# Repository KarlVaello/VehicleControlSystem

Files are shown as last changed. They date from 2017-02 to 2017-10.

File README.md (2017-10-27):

# Vehicle Control System

### What is VCS?
In modern vehicles almost 80% of the vehicle is controlled electronically. That's just VCS, a control system. Focused on electric vehicles but can be easily modified for other types.
VCS consists of several units and modules, all connected by an area network bus, based on rs-485 and my own [data protocol](https://github.com/KarlVaello/VCS/wiki/Unit-Communication-protocol), allowing modularization.
In this project you will find both the hardware and the software of each unit or module.

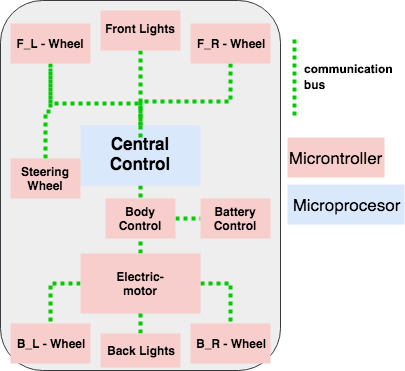
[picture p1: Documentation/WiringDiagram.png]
Wiring Diagram

 Electronic control units / modules
 
UNITS:
- CCU Central Control Unit
	- CCU Cluster Control Unit
	- CCU Central Control Unit
- EmCU Electric-motor Control Unit
- BCU Battery Control Unit

MODULES:
- CcCM Central-console Control Module
- SteeringWheel Control Module
- BCM Body Control Module
- BlCM Back-lights Control Module
- FlCM Front-lights Control Module

### SCREENSHOTS

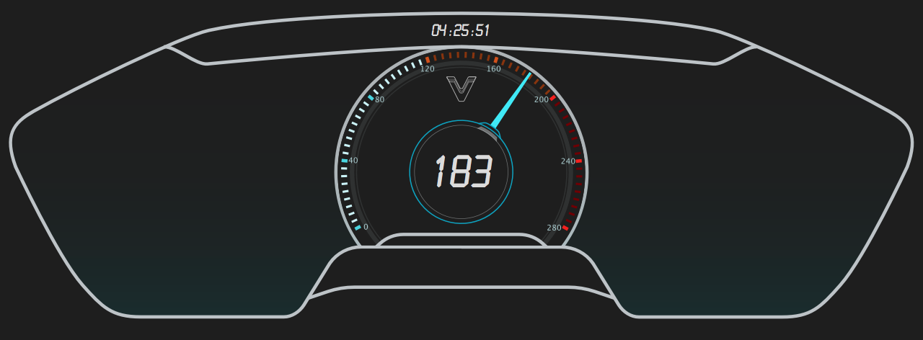
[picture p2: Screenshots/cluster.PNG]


BASE MODULE

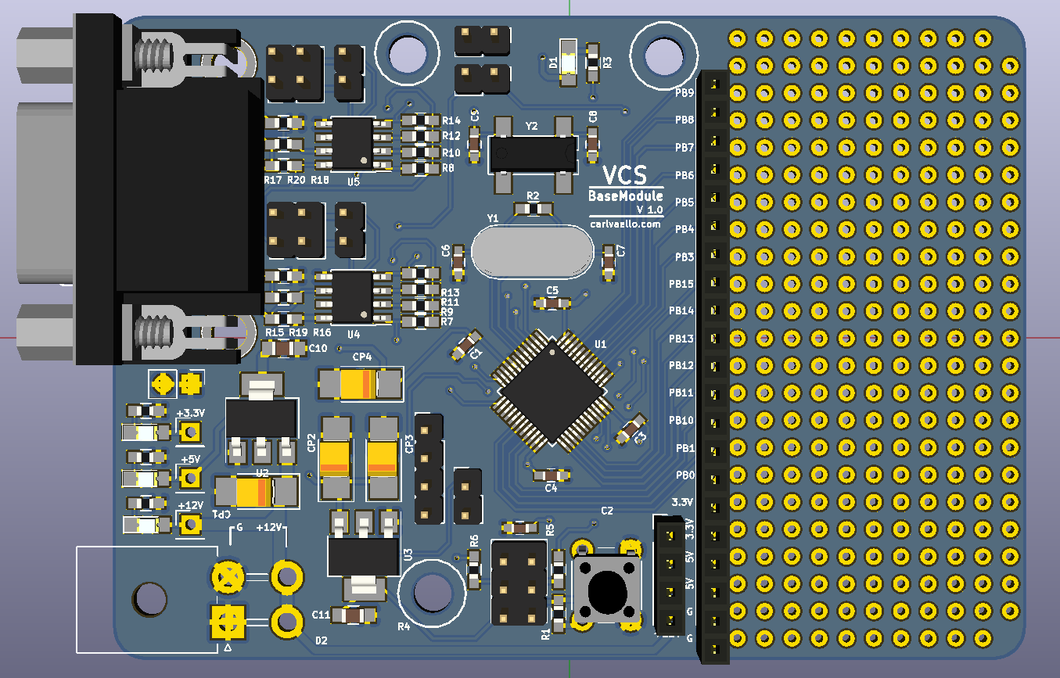
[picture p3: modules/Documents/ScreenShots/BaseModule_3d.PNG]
Base Module 3d

 
# Full Documentation

See the [WIKI](https://github.com/KarlVaello/VCS/wiki) for full documentation, examples, operational details and other information.

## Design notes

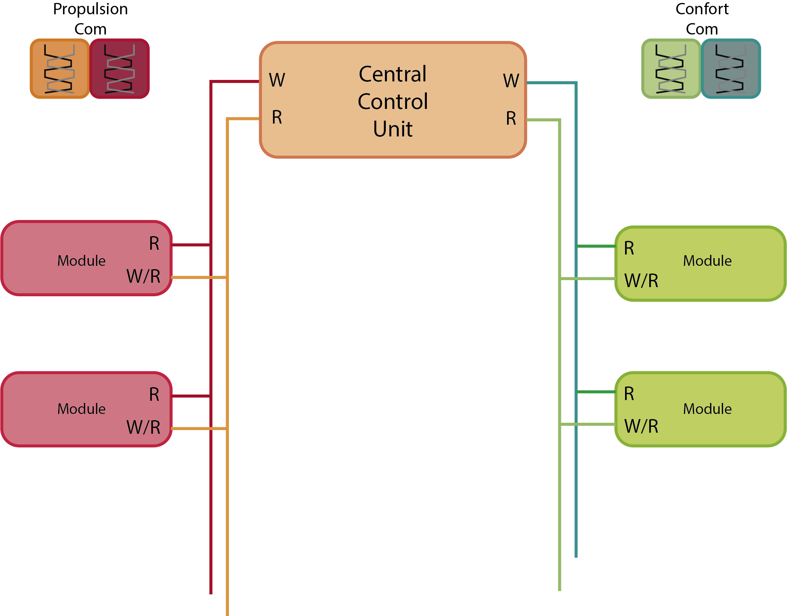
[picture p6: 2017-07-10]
Documentation/UnitCommunication_diagram.png

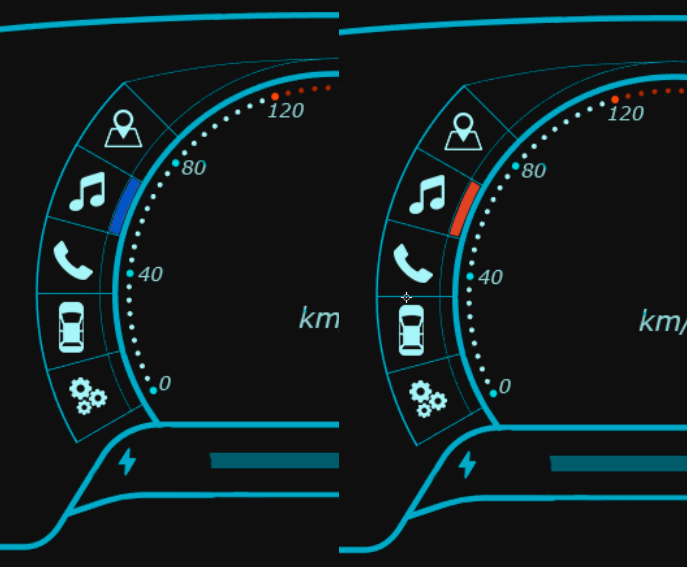
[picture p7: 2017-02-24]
Screenshots/UISketching.png

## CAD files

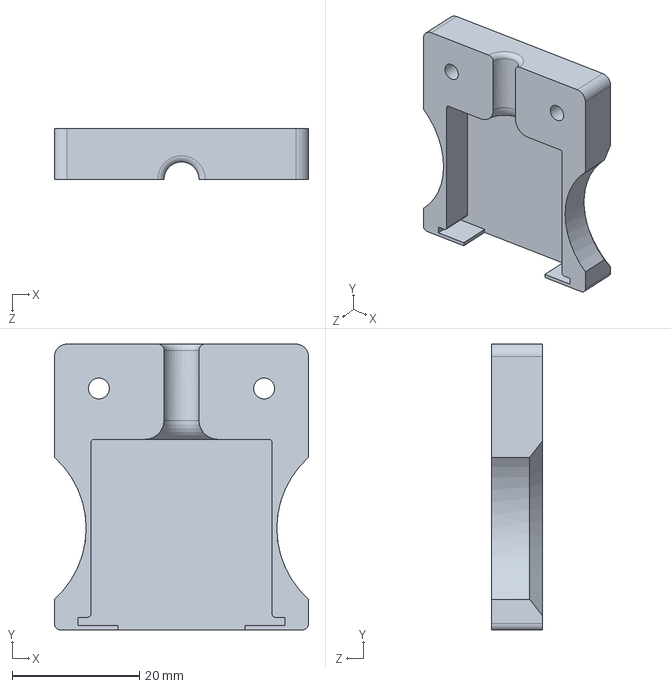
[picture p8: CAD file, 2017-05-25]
Other/DB9_SINGLE.SLDPRT
40.0 x 45.0 x 8.00 mm

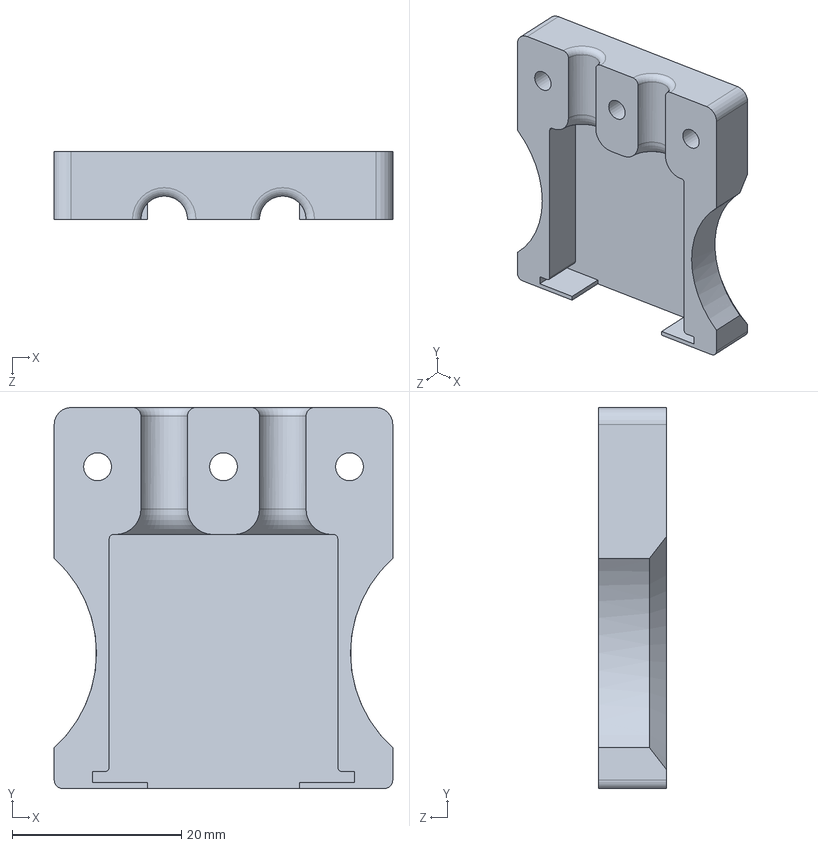
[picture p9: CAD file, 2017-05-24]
Other/DB9_DUAL.SLDPRT
40.0 x 45.0 x 8.00 mm

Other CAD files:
Other/DB9_DUAL.STL
Other/DB9_SINGLE.STL

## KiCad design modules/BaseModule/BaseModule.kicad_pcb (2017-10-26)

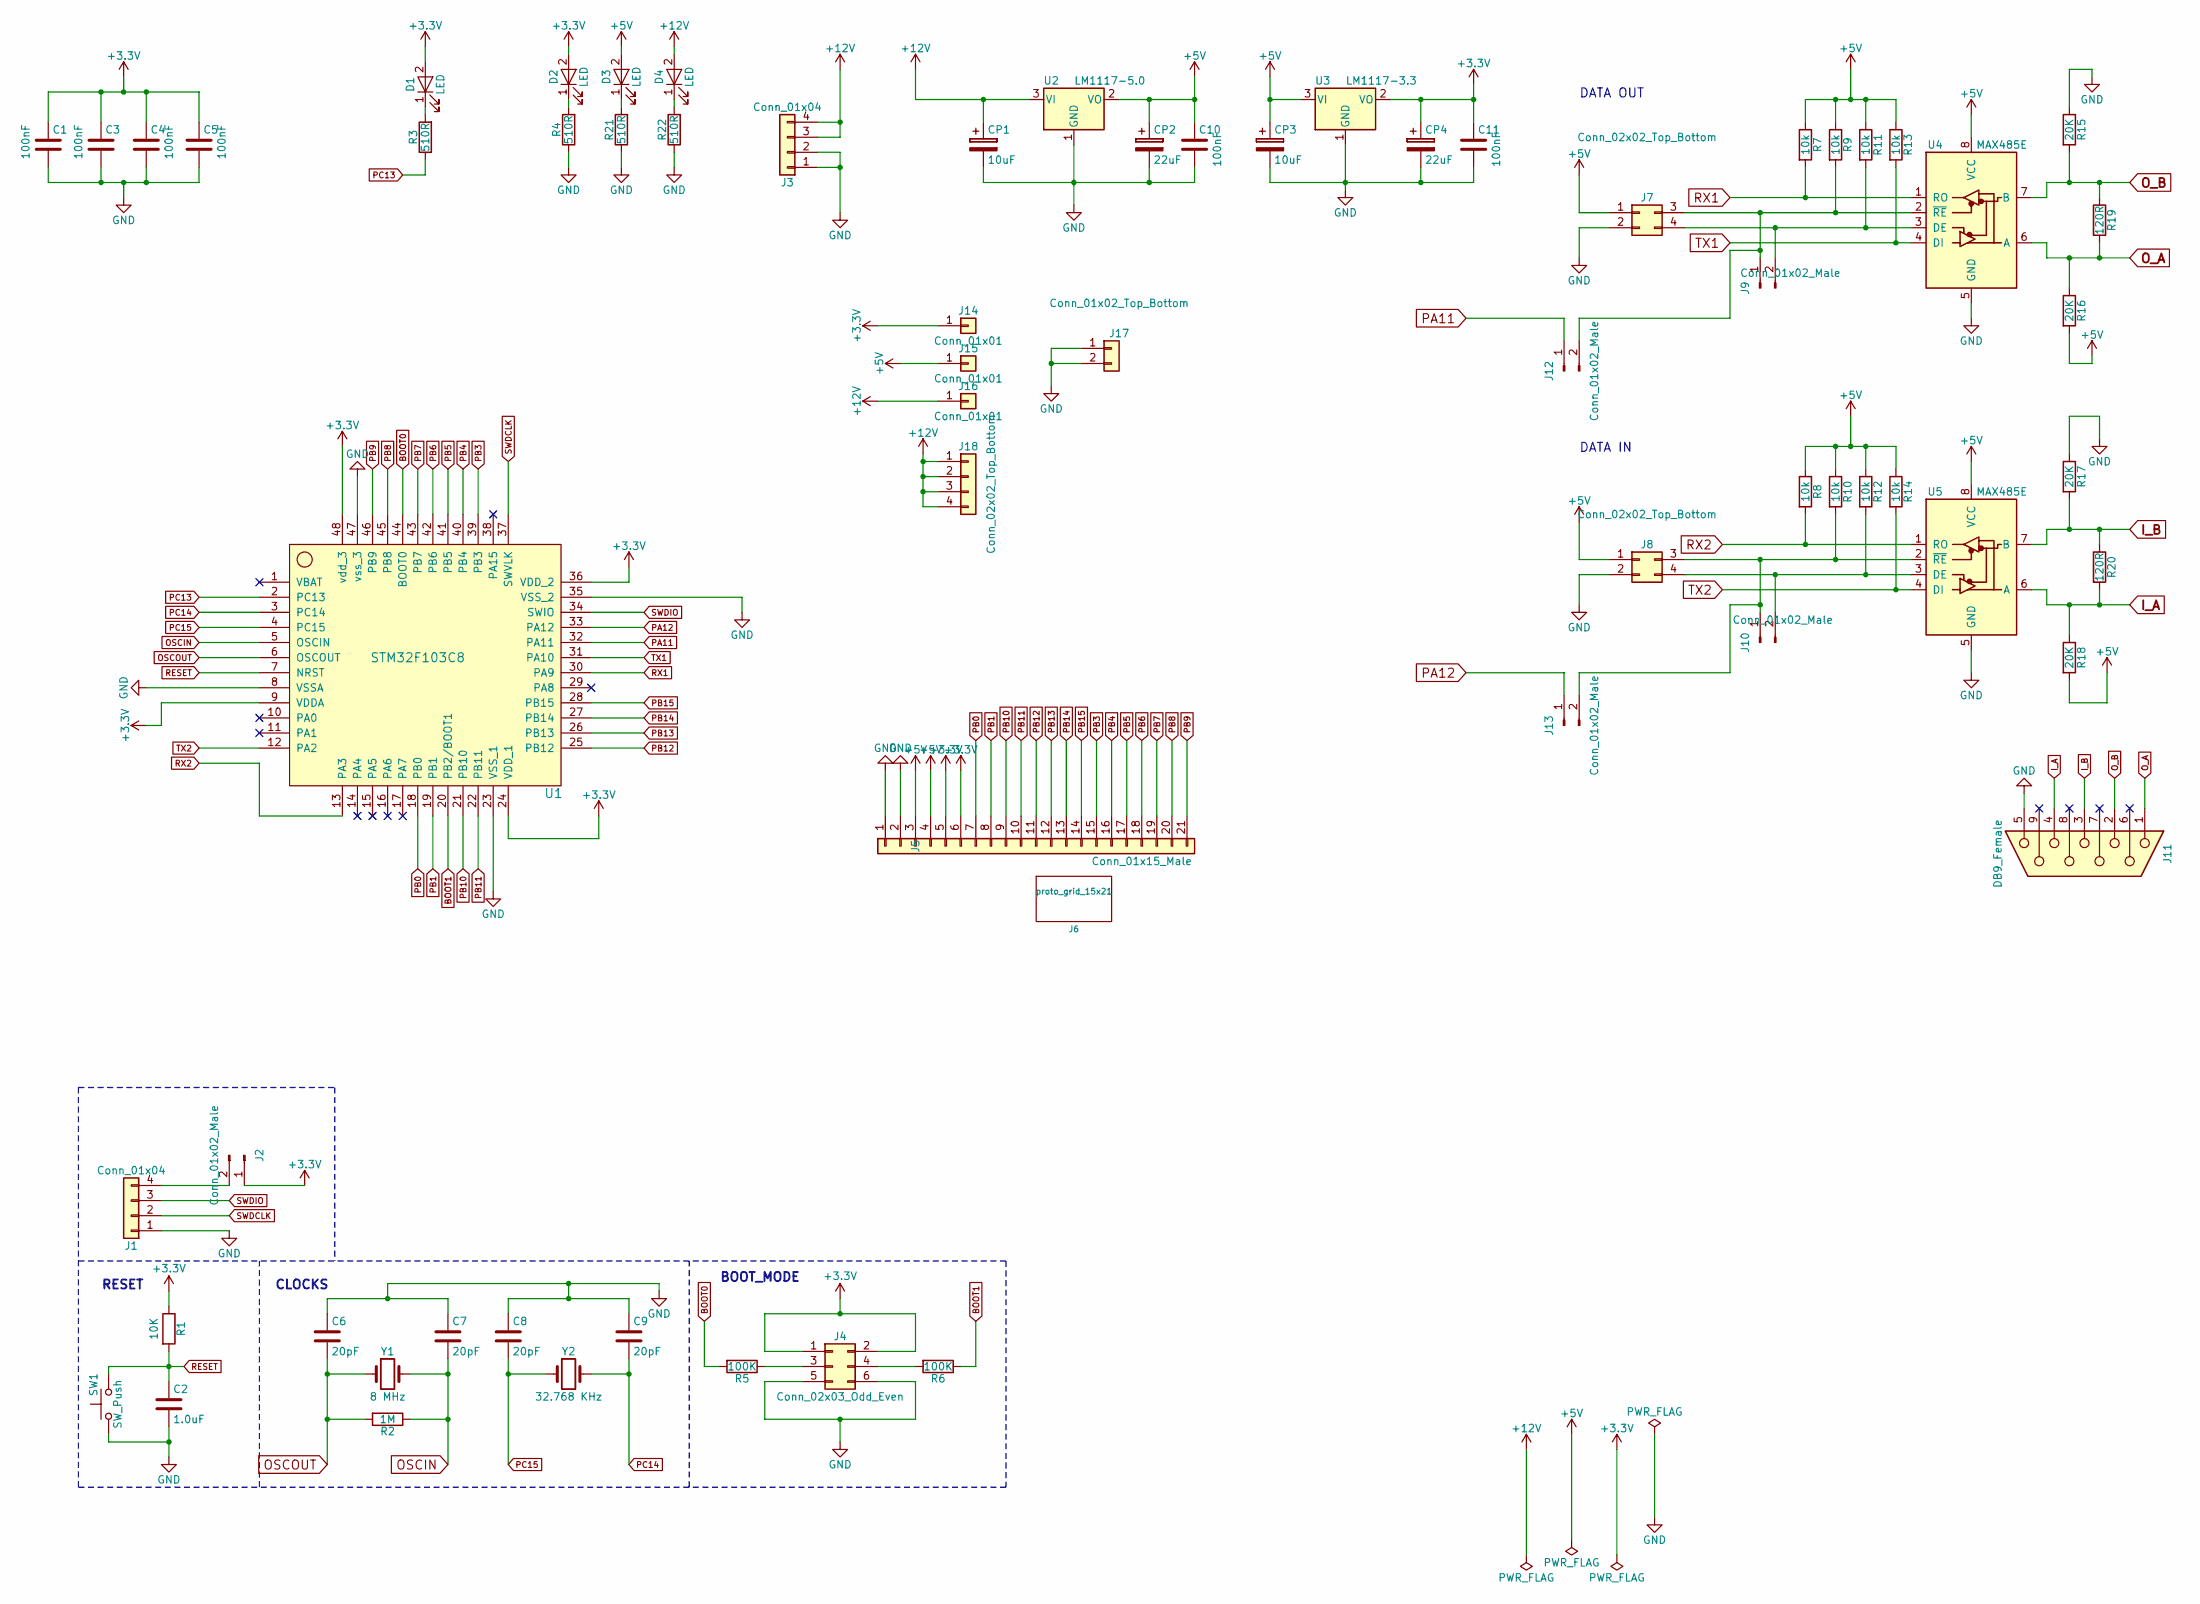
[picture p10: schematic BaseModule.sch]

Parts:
C1, C3, C4, C5: 100nF; C_0603_HandSoldering
C2: 1.0uF; C_0603_HandSoldering
C6, C7, C8, C9: 20pF; C_0603_HandSoldering
C10, C11: 100nF; C_0805_HandSoldering
CP1, CP3: 10uF; CP_Tantalum_Case-B_EIA-3528-21_Hand
CP2, CP4: 22uF; CP_Tantalum_Case-B_EIA-3528-21_Hand
D1, D2, D3, D4: LED; LED_0805_HandSoldering
J1: Conn_01x04; Pin_Header_Straight_1x04_Pitch2.54mm
J2, J9, J10, J12, J13: Conn_01x02_Male; Pin_Header_Straight_1x02_Pitch2.54mm
J3: Conn_01x04; Molex_MiniFit-JR-5569-04A2_2x02x4.20mm_Angled
J4: Conn_02x03_Odd_Even; Pin_Header_Straight_2x03_Pitch2.54mm
J5: Conn_01x15_Male; Socket_Strip_Straight_1x21_Pitch2.54mm
J6: proto_grid_15x21; grid
J7, J8: Conn_02x02_Top_Bottom; Pin_Header_Straight_2x02_Pitch2.54mm
J11: DB9_Female
J14, J15, J16: Conn_01x01; Pin_Header_Straight_1x01_Pitch2.54mm
J17: Conn_01x02_Top_Bottom; Pin_Header_Straight_1x02_Pitch2.54mm
J18: Conn_02x02_Top_Bottom; Socket_Strip_Straight_1x04_Pitch2.54mm
R1: 10K; R_0603_HandSoldering
R2: 1M; R_0603_HandSoldering
R3, R4, R21, R22: 510R; R_0603_HandSoldering
R5, R6: 100K; R_0603_HandSoldering
R7, R8, R9, R10, R11, R12, R13, R14: 10k; R_0603_HandSoldering
R15, R16, R17, R18: 20K; R_0603_HandSoldering
R19, R20: 120R; R_0603_HandSoldering
SW1: SW_Push; SW_PUSH_6mm_h8.5mm
U1: STM32F103C8; LQFP-48_7x7mm_Pitch0.5mm
U2: LM1117-5.0; SOT-223
U3: LM1117-3.3; SOT-223
U4, U5: MAX485E; SOIC-8_3.9x4.9mm_Pitch1.27mm
Y1: 8 MHz; Crystal_HC49-4H_Vertical
Y2: 32.768 KHz; Crystal_SMD_SeikoEpson_MC306-4pin_8.0x3.2mm_HandSoldering

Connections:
+3V3: C1.1, C3.1, C4.1, C5.1, C11.1, CP4.1, D1.2 (A), D2.2 (A), J2.1, J4.1, J4.2, J5.5, J5.6, J14.1, R1.1, U1.9 (VDDA), U1.24 (VDD_1), U1.36 (VDD_2), U1.48 (vdd_3), U3.2 (VO)
+5V: C10.1, CP2.1, CP3.1, D3.2 (A), J5.3, J5.4, J7.1, J8.1, J15.1, R7.1, R8.1, R9.1, R10.1, R11.1, R12.1, R13.1, R14.1, R16.2, R18.2, U2.2 (VO), U3.3 (VI), U4.8 (VCC), U5.8 (VCC)
+12V: CP1.1, D4.2 (A), J3.3, J3.4, J16.1, J18.1, J18.2, J18.3, J18.4, U2.3 (VI)
BOOT0: R5.2, U1.44 (BOOT0)
BOOT1: R6.1, U1.20 (PB2/BOOT1)
GND: C1.2, C2.2, C3.2, C4.2, C5.2, C6.1, C7.1, C8.1, C9.1, C10.2, C11.2, CP1.2, CP2.2, CP3.2, CP4.2, J1.1, J3.1, J3.2, J4.5, J4.6, J5.1, J5.2, J7.2, J8.2, J11.5, J17.1, J17.2, R4.1, R15.1, R17.1, R21.1, R22.1, SW1.1, U1.8 (VSSA), U1.23 (VSS_1), U1.35 (VSS_2), U1.47 (vss_3), U2.1 (GND), U3.1 (GND), U4.5 (GND), U5.5 (GND)
I_A: J11.4, R18.1, R20.2, U5.6 (A)
I_B: J11.3, R17.2, R20.1, U5.7 (B)
unnamed: D1.1 (K), R3.2
unnamed: D2.1 (K), R4.2
unnamed: D3.1 (K), R21.2
unnamed: D4.1 (K), R22.2
unnamed: J1.4, J2.2
unnamed: J4.3, R5.1
unnamed: J4.4, R6.2
unnamed: J7.4, J9.2, R11.2, U4.3 (DE)
unnamed: J8.3, J10.1, J13.2, R10.2, U5.2 (~RE)
unnamed: J8.4, J10.2, R12.2, U5.3 (DE)
unnamed: J7.3, J9.1, J12.2, R9.2, U4.2 (~RE)
OSCIN: C7.2, R2.1, U1.5 (OSCIN), Y1.2
OSCOUT: C6.2, R2.2, U1.6 (OSCOUT), Y1.1
O_A: J11.1, R16.1, R19.2, U4.6 (A)
O_B: J11.2, R15.2, R19.1, U4.7 (B)
PA11: J12.1, U1.32 (PA11)
PA12: J13.1, U1.33 (PA12)
PB0: J5.7, U1.18 (PB0)
PB1: J5.8, U1.19 (PB1)
PB3: J5.15, U1.39 (PB3)
PB4: J5.16, U1.40 (PB4)
PB5: J5.17, U1.41 (PB5)
PB6: J5.18, U1.42 (PB6)
PB7: J5.19, U1.43 (PB7)
PB8: J5.20, U1.45 (PB8~)
PB9: J5.21, U1.46 (PB9)
PB10: J5.9, U1.21 (PB10)
PB11: J5.10, U1.22 (PB11)
PB12: J5.11, U1.25 (PB12)
PB13: J5.12, U1.26 (PB13)
PB14: J5.13, U1.27 (PB14)
PB15: J5.14, U1.28 (PB15)
PC13: R3.1, U1.2 (PC13)
PC14: C9.2, U1.3 (PC14), Y2.2
PC15: C8.2, U1.4 (PC15), Y2.1
RESET: C2.1, R1.2, SW1.2, U1.7 (NRST)
RX1: R7.2, U1.30 (PA9), U4.1 (RO)
RX2: R8.2, U1.13 (PA3), U5.1 (RO)
SWDCLK: J1.2, U1.37 (SWVLK)
SWDIO: J1.3, U1.34 (SWIO)
TX1: R13.2, U1.31 (PA10), U4.4 (DI)
TX2: R14.2, U1.12 (PA2), U5.4 (DI)

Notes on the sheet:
DATA OUT
DATA IN
RESET
CLOCKS
BOOT_MODE

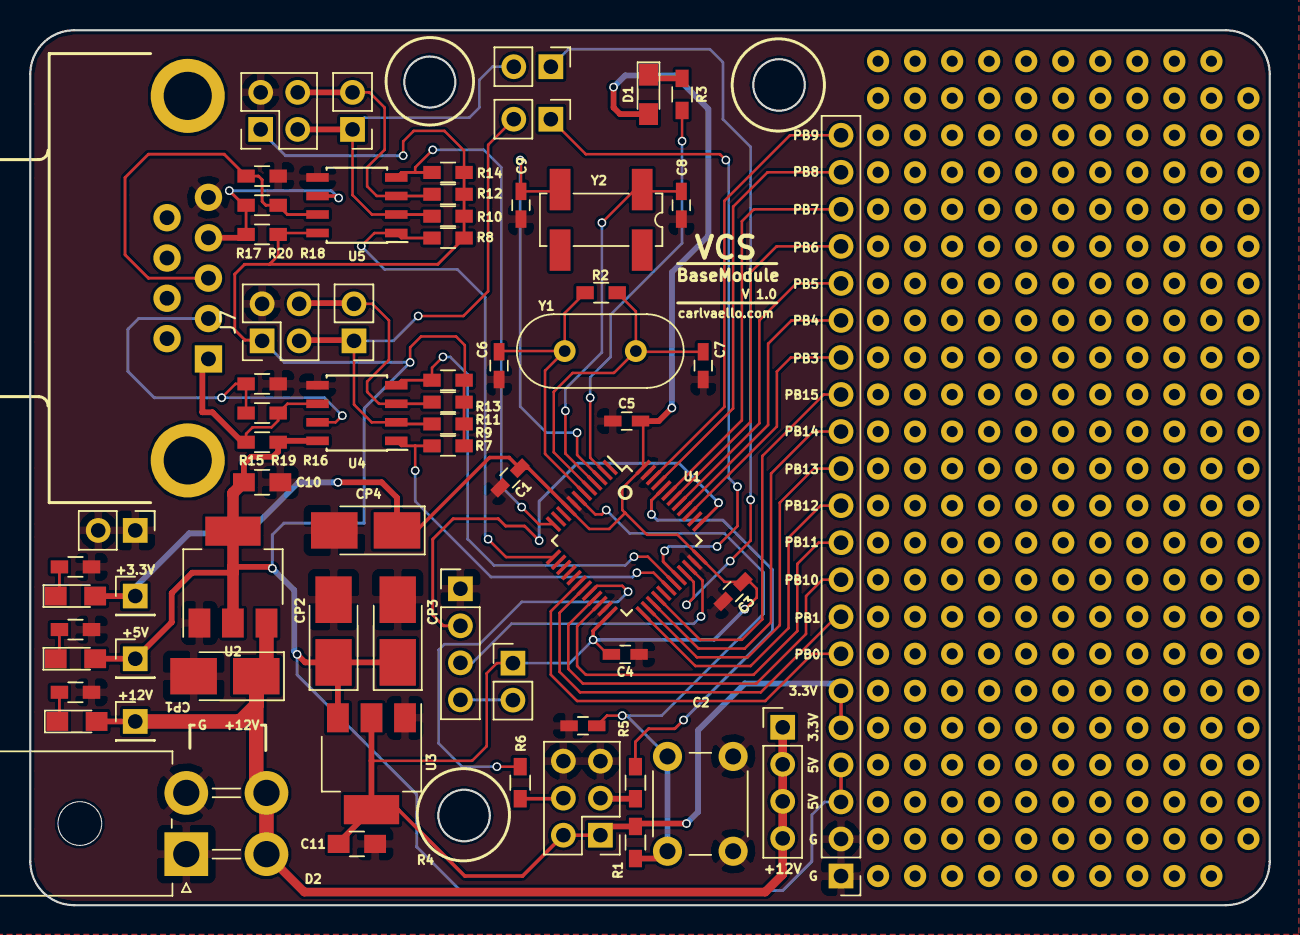
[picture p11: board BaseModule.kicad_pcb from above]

Board: 2 copper layers, 85.0 x 60.0 mm, 67 parts (0 on the bottom side), 50 nets.

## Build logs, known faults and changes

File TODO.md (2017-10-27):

## CCU - Central Control Unit

 ### TO DO (Software):
 Graphics
 - [ ] Complete UI graphics implementation
 - [x] speedPointer graphics implementation
 - [x] outline graphics implementation
 
 Communication
 - [ ] COMUNICATION between CCU and units. communicatión planning (physical laye rs-485)
 - [x] Bad data recived detection
 - [x] Propulsion Communication planning
 - [ ] Propulsion Communication wiki
 - [x] Propulsion Communication base code (that allow test)
 - [x] Propulsion Communication chek units
 - [x] FULL Propulsion Communication
 - [ ] Comfort Communication planning
 - [ ] Comfort Communication wiki
 - [ ] Comfort Communication base code (that allow test)
 - [ ] FULL communication working
 
 - [ ] FULL documentation and wiki about communication between units
 
 Warning / Errors
 - [ ] Warning and errors (UI whill show an icon when something fails and a message that explain de fail)

 	Warning and error are separated classes, every new error or warning is a new object. They will be store and we will be able to access to warnings and errors independtly.
 - [ ] Errors and Warling list and wiki 

 	Errors: 
 	- [ ] Communication error, some devicer not respond or is missing, depends of the missing devices it will show error or warning icon.

 	- [ ] P-Brake  error
 	- [ ] Spoiler error
	- [ ] Spoiler error
	- [ ] ...

 	Warnings:

 	- [ ] Battery warning

	more...

## CCU - Modules

 ### TO DO (SoftWare):
  - [x] Emiter base code
  - [X] Receiver base code
  - [X] Dual R/W base code
  - [ ] Data collion detecion

 ### TO DO (Hardware):

 - [X] BaseBoard planning (v1.0)
 - [X] BaseBoard Schematic(v1.0)
 - [X] BaseBoard Board(v1.0)
 - [X] FULL BaseBoard design(v1.0)
 - [ ] BaseBoard test PCB (asssembled and tested)(v1.0)
 - [ ] BaseBoard FINAL PCB (asssembled and tested)(v1.0)

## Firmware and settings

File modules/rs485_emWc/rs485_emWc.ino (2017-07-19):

/*
  Code that allow you to test dual rs-458, one to read incoming data and one to write data

*/
int incomingByte = 0;

int wSpeed = 0;
int a = true;

void setup() {
  Serial1.begin(115200);
  Serial2.begin(115200);
  pinMode(PC13, OUTPUT);
  pinMode(PB7, OUTPUT);

  digitalWrite(PC13, LOW);   // turn the LED on (HIGH is the voltage level)
  delay(100);              // wait for a second
  digitalWrite(PC13, HIGH);    // turn the LED off by making the voltage LOW
  delay(100);
  digitalWrite(PC13, LOW);   // turn the LED on (HIGH is the voltage level)
  delay(100);              // wait for a second
  digitalWrite(PC13, HIGH);    // turn the LED off by making the voltage LOW
  delay(100);
  digitalWrite(PC13, LOW);   // turn the LED on (HIGH is the voltage level)
  delay(100);              // wait for a second
  digitalWrite(PC13, HIGH);    // turn the LED off by making the voltage LOW
  delay(500);

  digitalWrite(PB7, HIGH);    //mx485 write mode
}


void loop() {

  if (a) {
    wSpeed = wSpeed + 130; 
    if (wSpeed >= 28000) { //280.00
      a = false;
    }
  } else {
    wSpeed = wSpeed - 130;
    if (wSpeed <= 0) {
      a = true;
    }
  }

  sendDataMessage(0, 1, 0, 0, 0, 0, 0, 0, 0, 0, 0);
  delay(40);

}

void sendDataMessage(int b0, int b1, int b2, int b3, int b4, int b5, int b6,
                     int b7, int b8, int b9, int b10) {

  Serial1.write(b0); //B0// reciverID (to who is send)
  Serial1.write(b1); //B1// senderID (who sends the message)
  Serial1.write(b2); //B2// dataID [(0x00)

  String fSpeed = convertIntTo16bitHex(wSpeed);
 
  Serial1.write(convertStringHexTo8bInt(fSpeed.substring(4, 8))); //B4// d1
  Serial1.write(convertStringHexTo8bInt(fSpeed.substring(0, 4))); //B3// d0

  Serial1.write(b5); //B5// d2
  Serial1.write(b6); //B6// d3
  Serial1.write(b7); //B7// d4
  Serial1.write(b8); //B8// d5
  Serial1.write(b9); //B9// d6
  Serial1.write(b10); //B10// d7

  float ercSum = b0 + b1 + b2 + convertStringHexTo8bInt(fSpeed.substring(4, 8)) + convertStringHexTo8bInt(fSpeed.substring(0, 4)) + b5 + b6 + b7 + b8 + b9 + b10;

  String ercSum_P1 = convertIntTo16bitHex (ercSum);
  int ercSum_P2 = convertStringHexTo8bInt(ercSum_P1.substring(0, 4));
  int ercSum_P3 = convertStringHexTo8bInt(ercSum_P1.substring(4, 8));
  Serial1.write(ercSum_P2); //B11// erc0
  Serial1.write(ercSum_P3); //B12// erc1
}


String convertIntTo16bitHex (int n) {
  float n0 = (float) n / 16.0f;
  float n1 = (float) n0 / 16.0f;
  float n2 = (float) n1 / 16.0f;
  float n3 = (float) n2 / 16.0f;

  int h0 = round(n) % 16;
  int h1 = int(n0) % 16;
  int h2 = int(n1) % 16;
  int h3 = int(n2) % 16;

  return "0x" + String(hexFormating(h3)) + String(hexFormating(h2)) + "0x" + String(hexFormating(h1)) + String(hexFormating(h0)) ;
  //0x320x10
}

char hexFormating(int eToHex) {
  char a = ' ';
  switch (eToHex) {
    case 0:
      a = '0';
      break;
    case 1:
      a = '1';
      break;
    case 2:
      a = '2';
      break;
    case 3:
      a = '3';
      break;
    case 4:
      a = '4';
      break;
    case 5:
      a = '5';
      break;
    case 6:
      a = '6';
      break;
    case 7:
      a = '7';
      break;
    case 8:
      a = '8';
      break;
    case 9:
      a = '9';
      break;
    case 10:
      a = 'A';
      break;
    case 11:
      a = 'B';
      break;
    case 12:
      a = 'C';
      break;
    case 13:
      a = 'D';
      break;
    case 14:
      a = 'E';
      break;
    case 15:
      a = 'F';
      break;
    default:
      break;
  }
  return a;
}

int convertStringHexTo8bInt(String stringHex) {

  int value = 0;

  String stringHexTrimg0 = stringHex.substring(3, 4);
  String stringHexTrimg1 = stringHex.substring(2, 3);

  if (stringHexTrimg0.equals("A")) {
    value = value + 10;
  } else if (stringHexTrimg0.equals("B")) {
    value = value + 11;
  } else if (stringHexTrimg0.equals("C")) {
    value = value + 12;
  } else if (stringHexTrimg0.equals("D")) {
    value = value + 13;
  } else if (stringHexTrimg0.equals("E")) {
    value = value + 14;
  } else if (stringHexTrimg0.equals("F")) {
    value = value + 15;
  } else {
    value = value + stringHexTrimg0.toInt();
  }

  if (stringHexTrimg1.equals("A")) {
    value = value + (10 * 16);
  } else if (stringHexTrimg1.equals("B")) {
    value = value + (11 * 16);
  } else if (stringHexTrimg1.equals("C")) {
    value = value + (12 * 16);
  } else if (stringHexTrimg1.equals("D")) {
    value = value + (13 * 16);
  } else if (stringHexTrimg1.equals("E")) {
    value = value + (14 * 16);
  } else if (stringHexTrimg1.equals("F")) {
    value = value + (15 * 16);
  } else {
    value = value + (stringHexTrimg1.toInt() * 16);
  }

  return value;
}

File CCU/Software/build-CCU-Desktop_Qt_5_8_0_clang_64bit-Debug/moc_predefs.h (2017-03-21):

#define OBJC_NEW_PROPERTIES 1
#define _LP64 1
#define __APPLE_CC__ 6000
#define __APPLE__ 1
#define __ATOMIC_ACQUIRE 2
#define __ATOMIC_ACQ_REL 4
#define __ATOMIC_CONSUME 1
#define __ATOMIC_RELAXED 0
#define __ATOMIC_RELEASE 3
#define __ATOMIC_SEQ_CST 5
#define __BIGGEST_ALIGNMENT__ 16
#define __BLOCKS__ 1
#define __BYTE_ORDER__ __ORDER_LITTLE_ENDIAN__
#define __CHAR16_TYPE__ unsigned short
#define __CHAR32_TYPE__ unsigned int
#define __CHAR_BIT__ 8
#define __CONSTANT_CFSTRINGS__ 1
#define __DBL_DECIMAL_DIG__ 17
#define __DBL_DENORM_MIN__ 4.9406564584124654e-324
#define __DBL_DIG__ 15
#define __DBL_EPSILON__ 2.2204460492503131e-16
#define __DBL_HAS_DENORM__ 1
#define __DBL_HAS_INFINITY__ 1
#define __DBL_HAS_QUIET_NAN__ 1
#define __DBL_MANT_DIG__ 53
#define __DBL_MAX_10_EXP__ 308
#define __DBL_MAX_EXP__ 1024
#define __DBL_MAX__ 1.7976931348623157e+308
#define __DBL_MIN_10_EXP__ (-307)
#define __DBL_MIN_EXP__ (-1021)
#define __DBL_MIN__ 2.2250738585072014e-308
#define __DECIMAL_DIG__ __LDBL_DECIMAL_DIG__
#define __DEPRECATED 1
#define __DYNAMIC__ 1
#define __ENVIRONMENT_MAC_OS_X_VERSION_MIN_REQUIRED__ 1090
#define __EXCEPTIONS 1
#define __FINITE_MATH_ONLY__ 0
#define __FLT_DECIMAL_DIG__ 9
#define __FLT_DENORM_MIN__ 1.40129846e-45F
#define __FLT_DIG__ 6
#define __FLT_EPSILON__ 1.19209290e-7F
#define __FLT_EVAL_METHOD__ 0
#define __FLT_HAS_DENORM__ 1
#define __FLT_HAS_INFINITY__ 1
#define __FLT_HAS_QUIET_NAN__ 1
#define __FLT_MANT_DIG__ 24
#define __FLT_MAX_10_EXP__ 38
#define __FLT_MAX_EXP__ 128
#define __FLT_MAX__ 3.40282347e+38F
#define __FLT_MIN_10_EXP__ (-37)
#define __FLT_MIN_EXP__ (-125)
#define __FLT_MIN__ 1.17549435e-38F
#define __FLT_RADIX__ 2
#define __FXSR__ 1
#define __GCC_ATOMIC_BOOL_LOCK_FREE 2
#define __GCC_ATOMIC_CHAR16_T_LOCK_FREE 2
#define __GCC_ATOMIC_CHAR32_T_LOCK_FREE 2
#define __GCC_ATOMIC_CHAR_LOCK_FREE 2
#define __GCC_ATOMIC_INT_LOCK_FREE 2
#define __GCC_ATOMIC_LLONG_LOCK_FREE 2
#define __GCC_ATOMIC_LONG_LOCK_FREE 2
#define __GCC_ATOMIC_POINTER_LOCK_FREE 2
#define __GCC_ATOMIC_SHORT_LOCK_FREE 2
#define __GCC_ATOMIC_TEST_AND_SET_TRUEVAL 1
#define __GCC_ATOMIC_WCHAR_T_LOCK_FREE 2
#define __GCC_HAVE_SYNC_COMPARE_AND_SWAP_1 1
#define __GCC_HAVE_SYNC_COMPARE_AND_SWAP_16 1
#define __GCC_HAVE_SYNC_COMPARE_AND_SWAP_2 1
#define __GCC_HAVE_SYNC_COMPARE_AND_SWAP_4 1
#define __GCC_HAVE_SYNC_COMPARE_AND_SWAP_8 1
#define __GNUC_GNU_INLINE__ 1
#define __GNUC_MINOR__ 2
#define __GNUC_PATCHLEVEL__ 1
#define __GNUC__ 4
#define __GNUG__ 4
#define __GXX_ABI_VERSION 1002
#define __GXX_EXPERIMENTAL_CXX0X__ 1
#define __GXX_RTTI 1
#define __GXX_WEAK__ 1
#define __INT16_C_SUFFIX__ 
#define __INT16_FMTd__ "hd"
#define __INT16_FMTi__ "hi"
#define __INT16_MAX__ 32767
#define __INT16_TYPE__ short
#define __INT32_C_SUFFIX__ 
#define __INT32_FMTd__ "d"
#define __INT32_FMTi__ "i"
#define __INT32_MAX__ 2147483647
#define __INT32_TYPE__ int
#define __INT64_C_SUFFIX__ LL
#define __INT64_FMTd__ "lld"
#define __INT64_FMTi__ "lli"
#define __INT64_MAX__ 9223372036854775807LL
#define __INT64_TYPE__ long long int
#define __INT8_C_SUFFIX__ 
#define __INT8_FMTd__ "hhd"
#define __INT8_FMTi__ "hhi"
#define __INT8_MAX__ 127
#define __INT8_TYPE__ signed char
#define __INTMAX_C_SUFFIX__ L
#define __INTMAX_FMTd__ "ld"
#define __INTMAX_FMTi__ "li"
#define __INTMAX_MAX__ 9223372036854775807L
#define __INTMAX_TYPE__ long int
#define __INTMAX_WIDTH__ 64
#define __INTPTR_FMTd__ "ld"
#define __INTPTR_FMTi__ "li"
#define __INTPTR_MAX__ 9223372036854775807L
#define __INTPTR_TYPE__ long int
#define __INTPTR_WIDTH__ 64
#define __INT_FAST16_FMTd__ "hd"
#define __INT_FAST16_FMTi__ "hi"
#define __INT_FAST16_MAX__ 32767
#define __INT_FAST16_TYPE__ short
#define __INT_FAST32_FMTd__ "d"
#define __INT_FAST32_FMTi__ "i"
#define __INT_FAST32_MAX__ 2147483647
#define __INT_FAST32_TYPE__ int
#define __INT_FAST64_FMTd__ "ld"
#define __INT_FAST64_FMTi__ "li"
#define __INT_FAST64_MAX__ 9223372036854775807L
#define __INT_FAST64_TYPE__ long int
#define __INT_FAST8_FMTd__ "hhd"
#define __INT_FAST8_FMTi__ "hhi"
#define __INT_FAST8_MAX__ 127
#define __INT_FAST8_TYPE__ signed char
#define __INT_LEAST16_FMTd__ "hd"
#define __INT_LEAST16_FMTi__ "hi"
#define __INT_LEAST16_MAX__ 32767
#define __INT_LEAST16_TYPE__ short
#define __INT_LEAST32_FMTd__ "d"
#define __INT_LEAST32_FMTi__ "i"
#define __INT_LEAST32_MAX__ 2147483647
#define __INT_LEAST32_TYPE__ int
#define __INT_LEAST64_FMTd__ "ld"
#define __INT_LEAST64_FMTi__ "li"
#define __INT_LEAST64_MAX__ 9223372036854775807L
#define __INT_LEAST64_TYPE__ long int
#define __INT_LEAST8_FMTd__ "hhd"
#define __INT_LEAST8_FMTi__ "hhi"
#define __INT_LEAST8_MAX__ 127
#define __INT_LEAST8_TYPE__ signed char
#define __INT_MAX__ 2147483647
#define __LDBL_DECIMAL_DIG__ 21
#define __LDBL_DENORM_MIN__ 3.64519953188247460253e-4951L
#define __LDBL_DIG__ 18
#define __LDBL_EPSILON__ 1.08420217248550443401e-19L
#define __LDBL_HAS_DENORM__ 1
#define __LDBL_HAS_INFINITY__ 1
#define __LDBL_HAS_QUIET_NAN__ 1
#define __LDBL_MANT_DIG__ 64
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

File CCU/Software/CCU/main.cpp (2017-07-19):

#include <QApplication>

#include "cluster.h"
#include <QtSvg/QtSvg>
#include <QtSvg/QSvgRenderer>
#include <cameraStream.h>
#include <unitCommunication.h>
#include <infotainment.h>

int main(int argc, char *argv[])
{
    QApplication app(argc, argv);
    Infotainment *infotainment = new Infotainment();

    UnitCommunication *centralControlUnit_COM = new UnitCommunication(infotainment);
    centralControlUnit_COM->startCom(infotainment);

    Cluster *cluster = new Cluster(0,centralControlUnit_COM,infotainment);

    //CameraStream *leftCamera = new CameraStream("left");
    //leftCamera->show();

    //CameraStream *rightCamera = new CameraStream("right");
    //rightCamera->show();


    cluster->show();
    return app.exec();
}

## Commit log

2017-02-21 Minor changes. Wiring diagram update
    Minor changes. Wiring diagram update
2017-02-25 Wiring diagram update
    Wiring diagram update
2017-02-26 Update WiringDiagram
2017-02-26 new wiringdiagram
2017-02-26 New EmCU folder and KiCad projecto
    New EmCU folder and KiCad projecto
    [EmCU.kicad_pcb, EmCU.sch]
2017-02-27 STM32 Documentation. STM32 Core board update
    [EmCU.sch, STM32Core.kicad_pcb, STM32Core.sch]
2017-04-04 New Classes to communicate between units
    New UnitCommunication class, data exchange.
    New Infotainment class, data holder.
    More info on the wiki.
    cameraCaptureBuffer and cameraSteam are new too but there are on a
    standby because it’s need a specific hardware (camera) selection to
    continue develop it. The hardware determines almost all code work.
2017-05-13 folders reorganized, arduino stm32 code rs-485 for test communications
    [STM32Core.kicad_pcb, STM32Core.sch]
2017-05-24 DB9 connector
    [DB9_DUAL.SLDPRT, DB9_DUAL.STL]
2017-05-24 DB9_SINGLE connector
    [DB9_SINGLE.SLDPRT, DB9_SINGLE.STL]
2017-05-25 DB9_single updated
    [DB9_SINGLE.SLDPRT]
2017-05-25 new db9 single stl
    [DB9_SINGLE.STL]
2017-06-27 Added Base module
    Added Base Module as de base circuit of every module with stm32
    microcontroller
    [BaseModule.brd, BaseModule.sch]
2017-06-28 BaseBoard updates + hardware documentation
    [BaseModule.brd, BaseModule.sch]
2017-07-07 base module update
    base module update
    [BaseModule.brd, BaseModule.sch]
2017-07-16 unitCommunication Updates
    Now unitCommunication just hold diferente communication (propulsion,
    confort…). Even different communication had their own new class. The
    just manage their own communication and in different threats.
2017-08-02 BaseModule pcb updates
    [BaseModule.brd, BaseModule.sch]
2017-10-24 BaseModule updates (new board)
    Made with kicad
    [BaseModule.brd, BaseModule.kicad_pcb]
2017-10-26 BaseModule updates and documentation updates
    [BaseModule-B.Cu.gbr, BaseModule-B.Mask.gbr, BaseModule-B.Paste.gbr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]
